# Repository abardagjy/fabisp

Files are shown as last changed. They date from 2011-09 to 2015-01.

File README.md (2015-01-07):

# FabISP



_FabISPkey V1.0 (current revision is V2.3, after V2.2, V2.1, V2.0 and V1.1)_

The geneology of the FabISP design is interesting in its own right; Neil's [FabISP](http://academy.cba.mit.edu/classes/electronics_production/index.html) is based on David Mellis's [FabISP](http://fab.cba.mit.edu/content/projects/fabisp/) which is based on Limor's [USBTinyISP](http://www.ladyada.net/make/usbtinyisp/index.html) which is based on Dick Streefland's [USBTiny](http://dicks.home.xs4all.nl/avr/usbtiny/).

## FabISPkey

### Design

I decided I could make a few tweaks to the design, electrically and mechanically. First, I tried out my mechanical modifications before I dove too deeply into electrical modification. Next, I redrew David's schematic in EagleCAD. I replaced the USB connector with a board edge USB connector from the SparkFun library. I also replaced the crystal with one that I had on hand, which ended up being a mistake, and in later designs I used the one in the Fab inventory, which is smaller. All the parts can be found in the standard fab inventory.

<table align="center">
<tbody>
<tr>
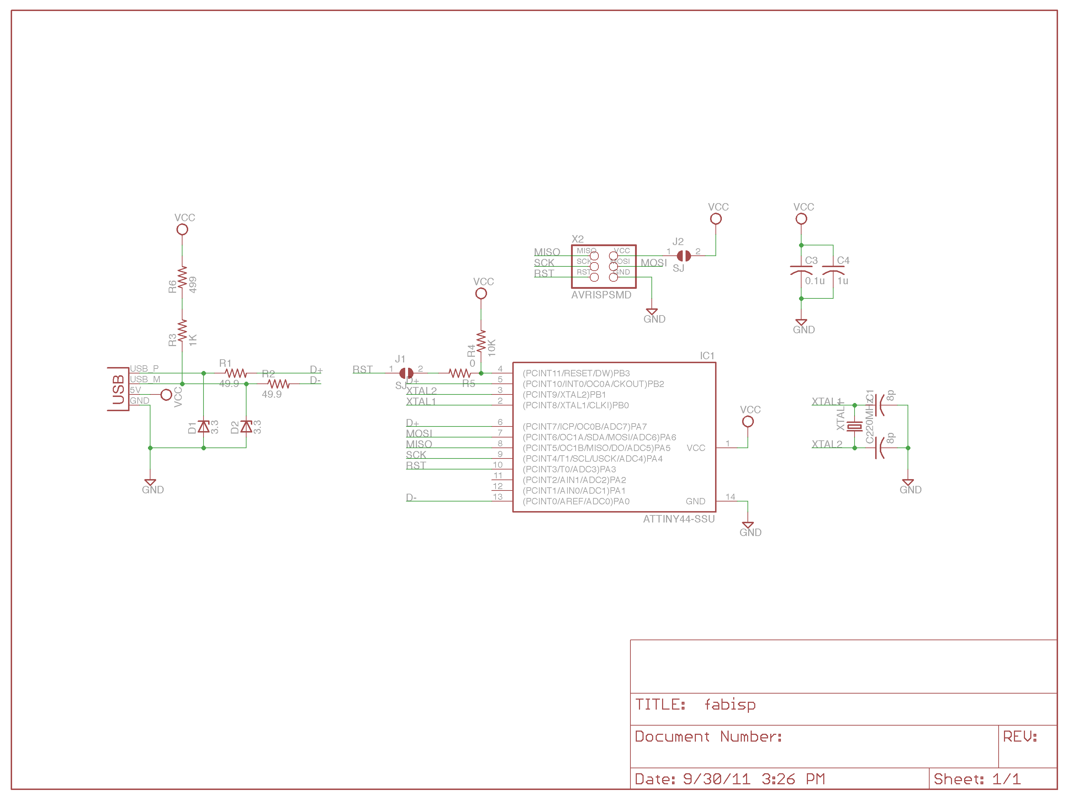
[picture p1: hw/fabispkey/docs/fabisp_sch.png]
fabispkey_sch
<td></td>
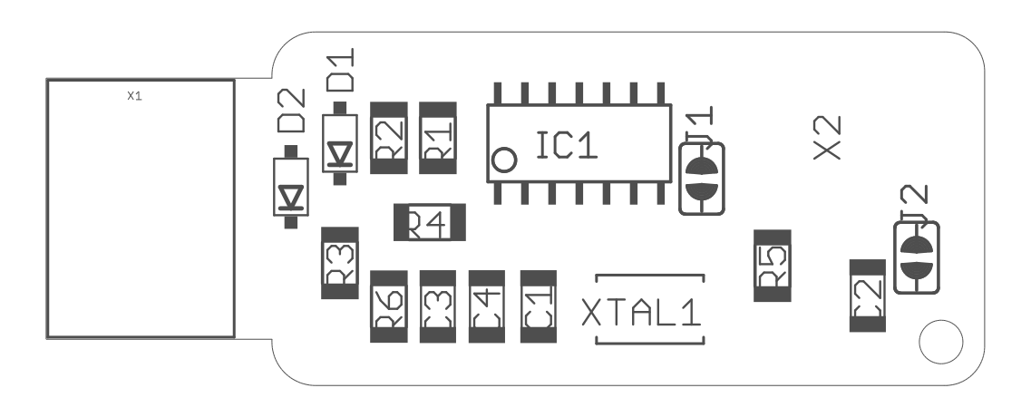
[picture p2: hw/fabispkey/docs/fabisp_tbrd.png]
fabispkey_tbrd
<td></td>
</tr>
</tbody>
</table>

_Version 2.3 FabISPkey, schematic and assembly drawing_

In general, I made the total footprint a little smaller and replaced the mini-USB connector with a board connector. In a second design, I added a level shifter to accommodate programming of low voltage (1.8V) targets.

Some notes: I use a ground pour, because I figure if I'm going to have extra copper on my board, I'd like to know what it's connected to. The pour has 0.020 spacing, so slightly more than one pass with a 0.015 endmill cuts it out. 

### Fabrication

Because the connector, the design requires complete copper removal (-1 contours flag). Also, the board connector is a little wiggily, so, it's sometimes helpful to glue or tape a small (0.010") shim on the underside of the connector. I use a piece of an old credit card and the same double sided tape used to affix the boards to the Modella.

When populating the board, be sure to observe polarity on for the zeners and the ATtiny. I did not leave thermal reliefs on the ground pour (I find they don't come out well on the Modella, also decreases cut time). Because there are no thermals, be sure to avoid cold solder joints on all components connected to the ground plane. 

<table align="center">
<tbody>
<tr>
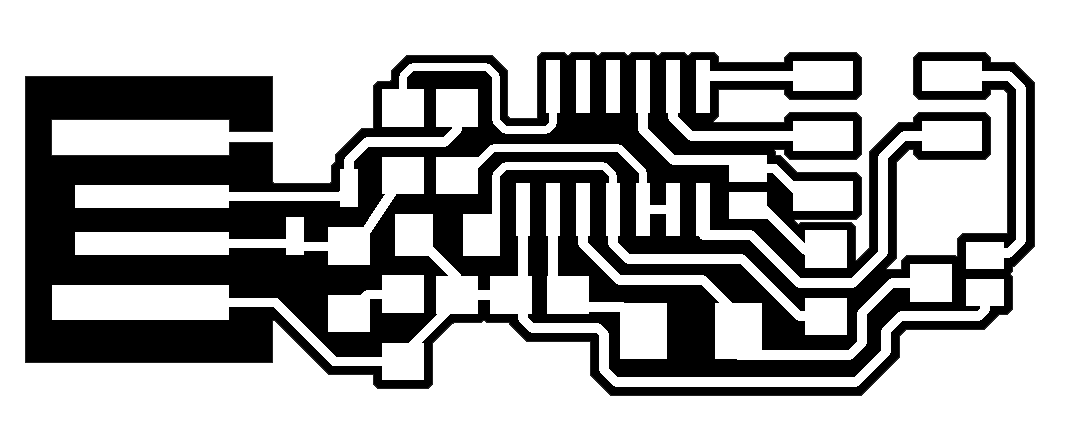
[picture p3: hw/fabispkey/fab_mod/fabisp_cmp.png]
fabispkey_cmp
<td></td>
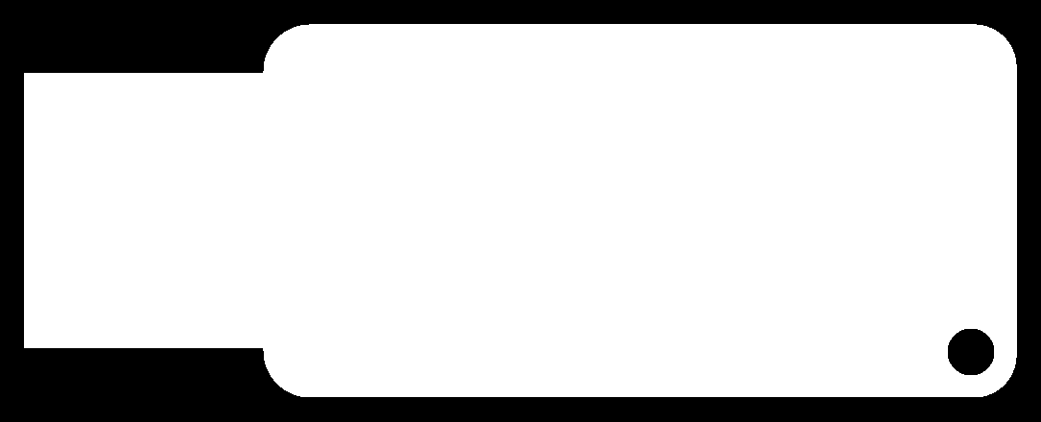
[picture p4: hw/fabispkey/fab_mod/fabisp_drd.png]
fabispkey_drd
<td></td>
</tr>
</tbody>
</table>

_Version 2.3 FabISPkey_

If you'd like to play along at home, you can grab fabbable PNGs above and you can get the design files in this content directory.

### Programming

Since my design is electrically similar to Neil and David's, programming is very similar. 

1.  Solder the reset jumper (the one closest to the processor)
2.  Power the board (using a USB port, or USB charger)
3.  Using a standard programming cable, connect your programmer to be to another programmer (connect Pin 1 to Pin 1, Pin 2 to 2 and so on)
<li>Program it with another programmer (make hex, make fuse, make program)
4.  Unplug the programming cable, remove power, and desolder the jumper
5.  Spawn more programmers!

## FabISPlokey

One of the main motivations of the board re-design was to incorporate a level shifter to allow the programming of 1.8V targets. This is a particularly important feature (especially for this class) because it allows the use of a single cell to power designs.

The Lokey dispenses with the 3.3V zeners and adds a 3.3V regulator (in the Fab inventory). The microcontroller now runs on 3.3V, no need for the zeners to make it USB compliant. 

Having a 3.3V Vcc is required to use the level shifter I selected, the Texas Instruments [TXB0104](http://www.ti.com/lit/ds/symlink/txb0104.pdf). The TX0104 is available in a 14 SOIC package (which is easily fabricatable on the Modella), and if you ask nicely, TI will happily sample a few parts to you. 

<table align="center">
<tbody>
<tr>
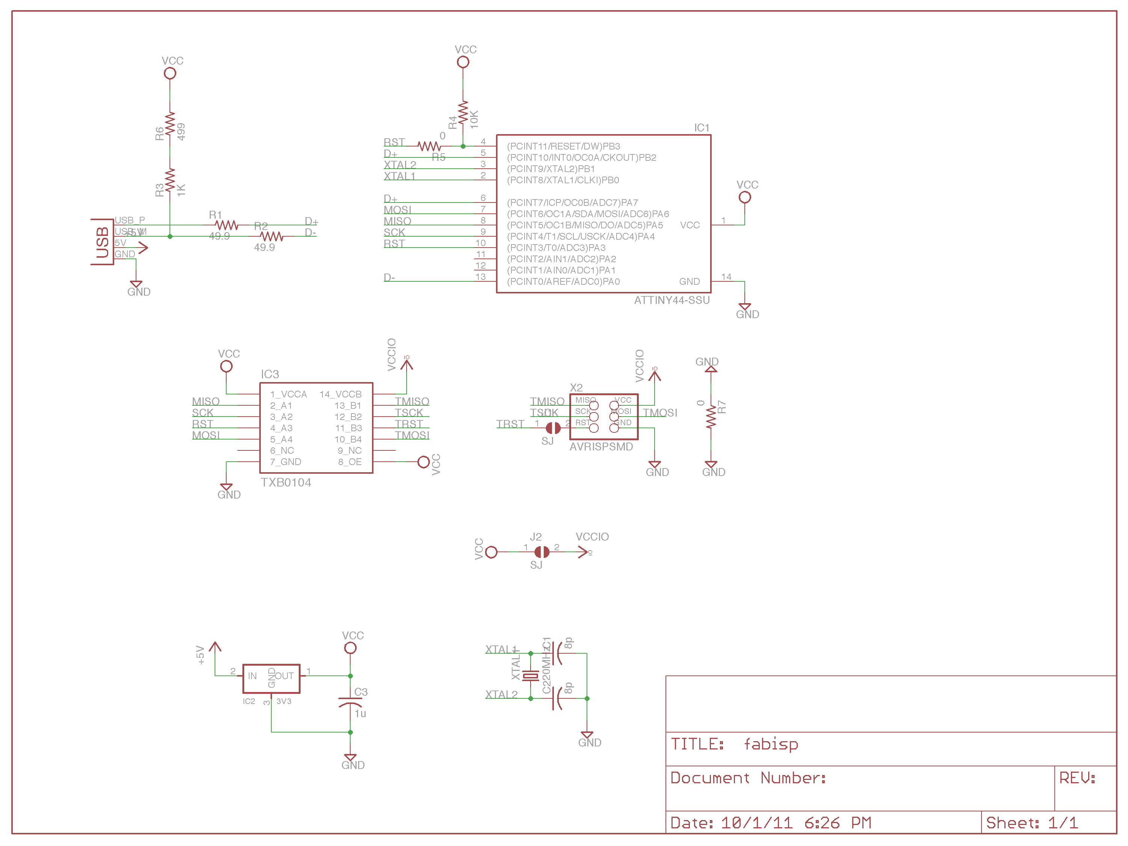
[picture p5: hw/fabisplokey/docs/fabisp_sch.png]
fabisplokey_sch
<td></td>
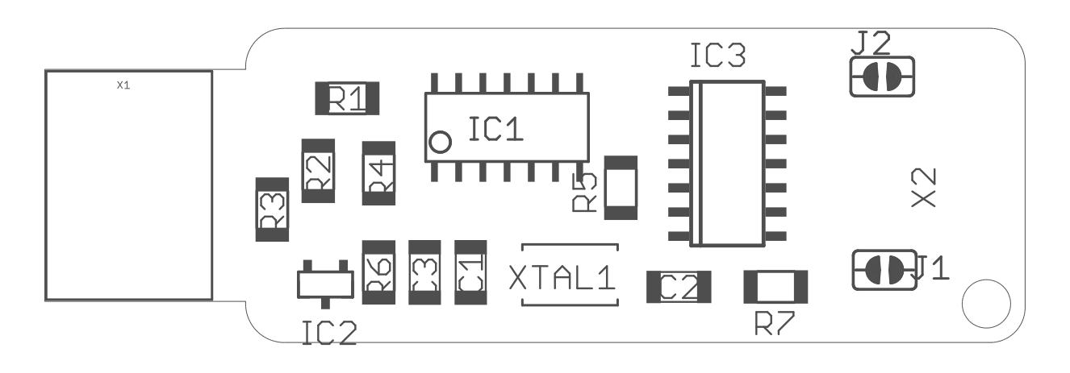
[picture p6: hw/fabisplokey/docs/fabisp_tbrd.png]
fabisplokey_tbrd
<td></td>
</tr>
</tbody>
</table>

_Version 2.3 FabISPkey, schematic and assembly drawing_

<table align="center"><tbody>
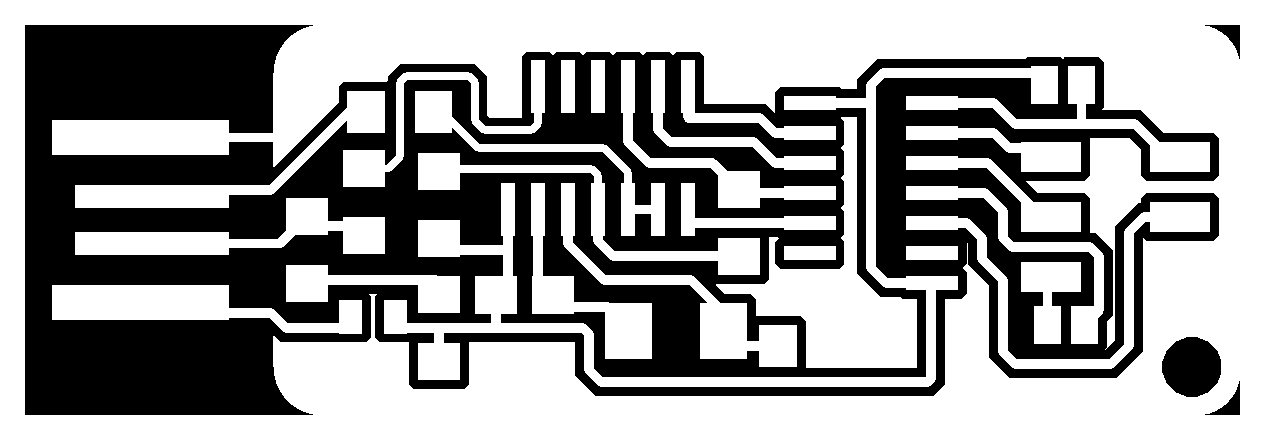
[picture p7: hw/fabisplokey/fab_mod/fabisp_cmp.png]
fabisplokey_cmp
<tr><td></td>
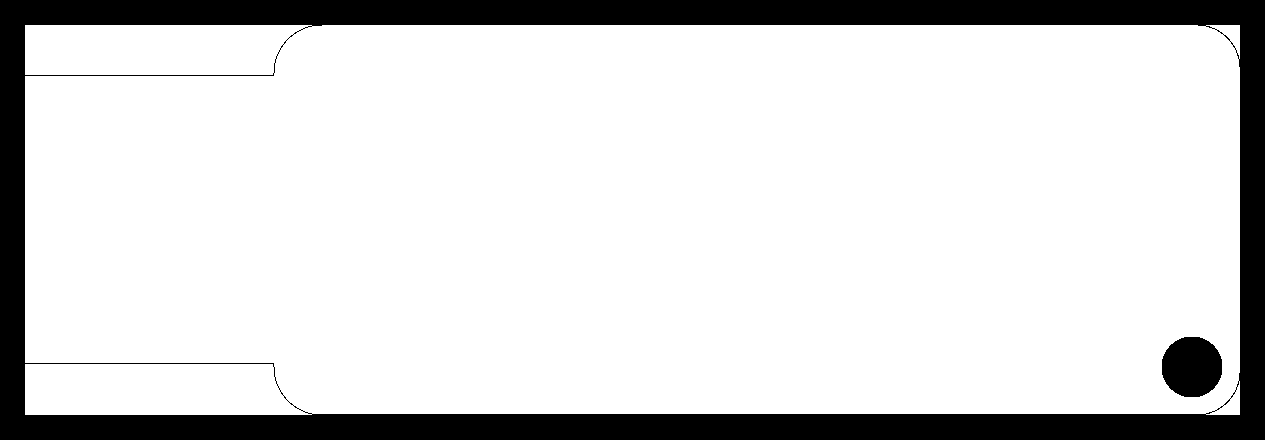
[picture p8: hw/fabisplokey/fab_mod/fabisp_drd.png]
fabisplokey_drd
<td></td>
</tr>
</tbody>
</table>

_Version 2.1 FabISPlokey_

I do not have any 1.8V targets to try this design on and should be considered an untested reference design (though it should work), Nevertheless, if you'd like to try it out yourself, you can grab the PNGs above or from the repo (it's in the same project as the Key).

_Created by [Andy Bardagjy](http://bardagjy.com) 12/19/2011, modified 1/7/2015_

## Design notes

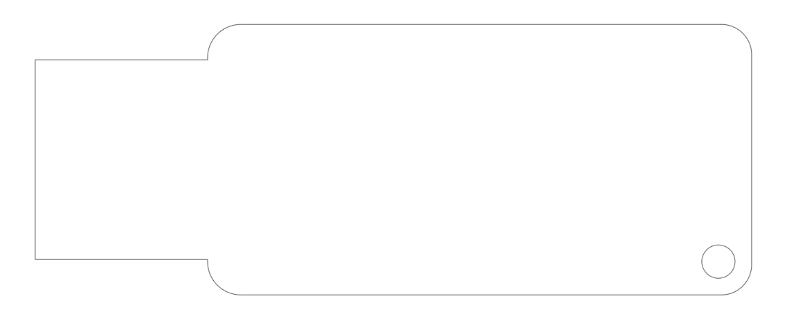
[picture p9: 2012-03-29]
hw/fabispkey/docs/fabisp_bbrd.png

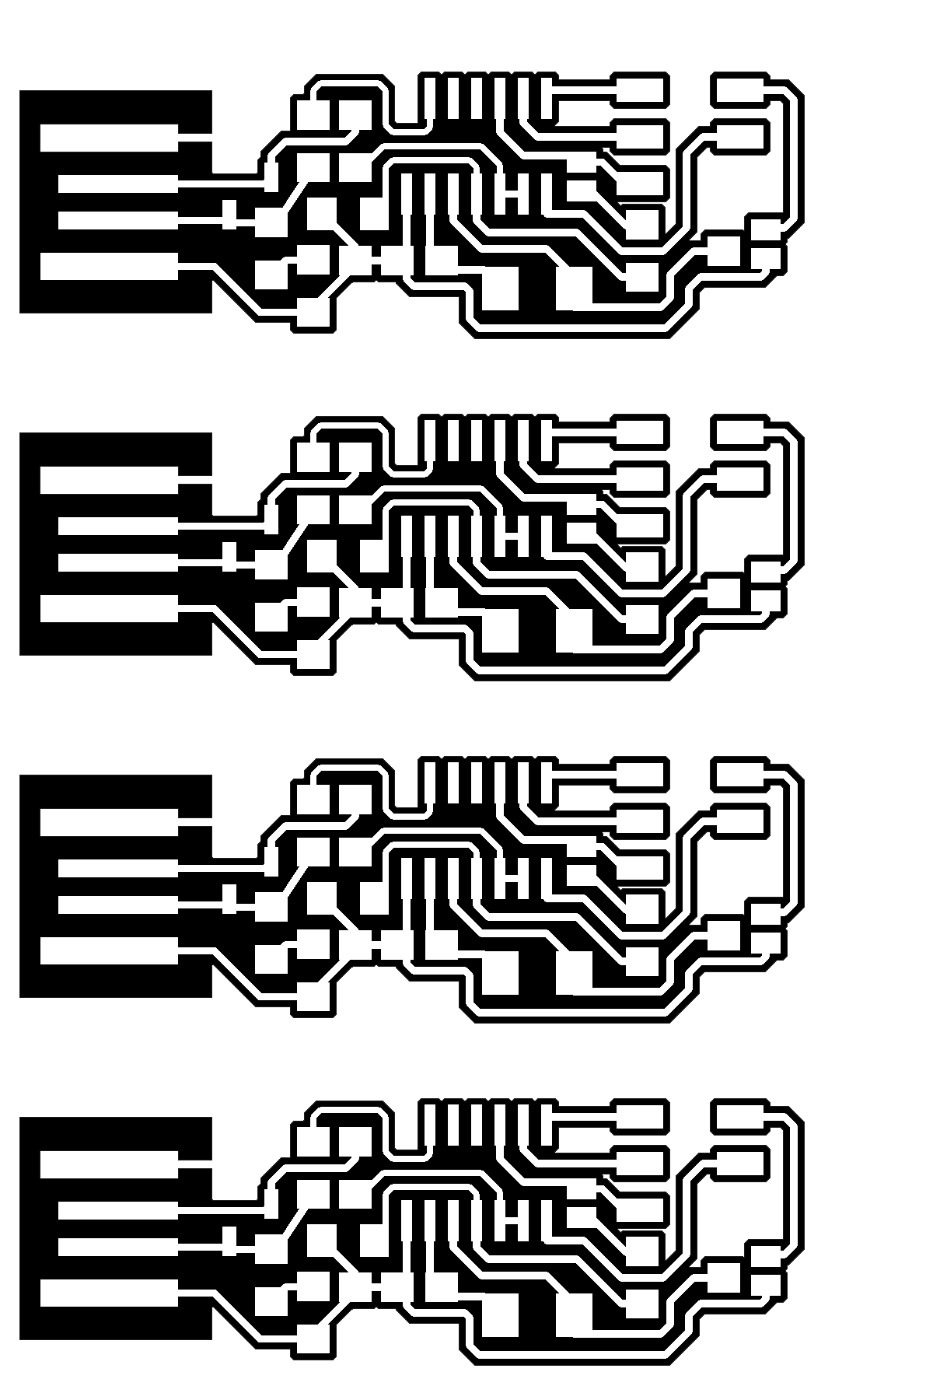
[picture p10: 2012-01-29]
hw/fabispkey/fab_mod/4up_cmp.png

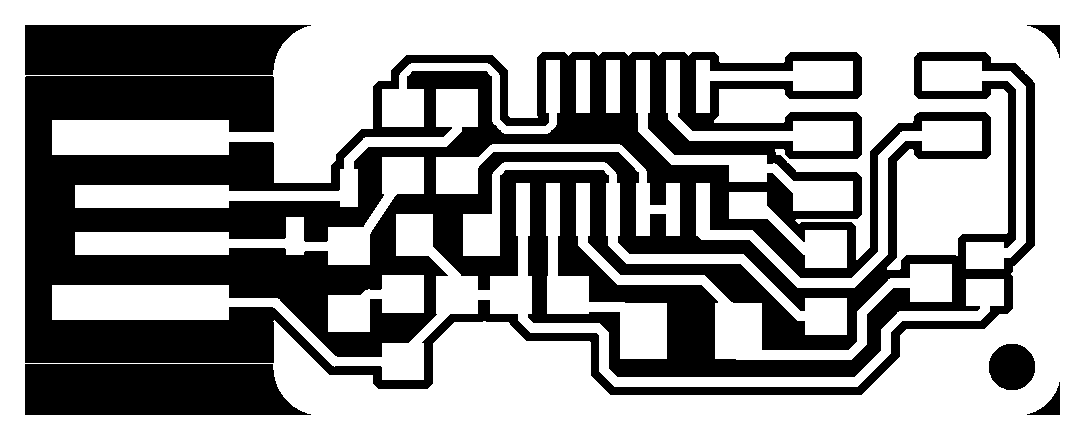
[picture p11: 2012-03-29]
hw/fabispkey/fab/fabisp_cmp.png

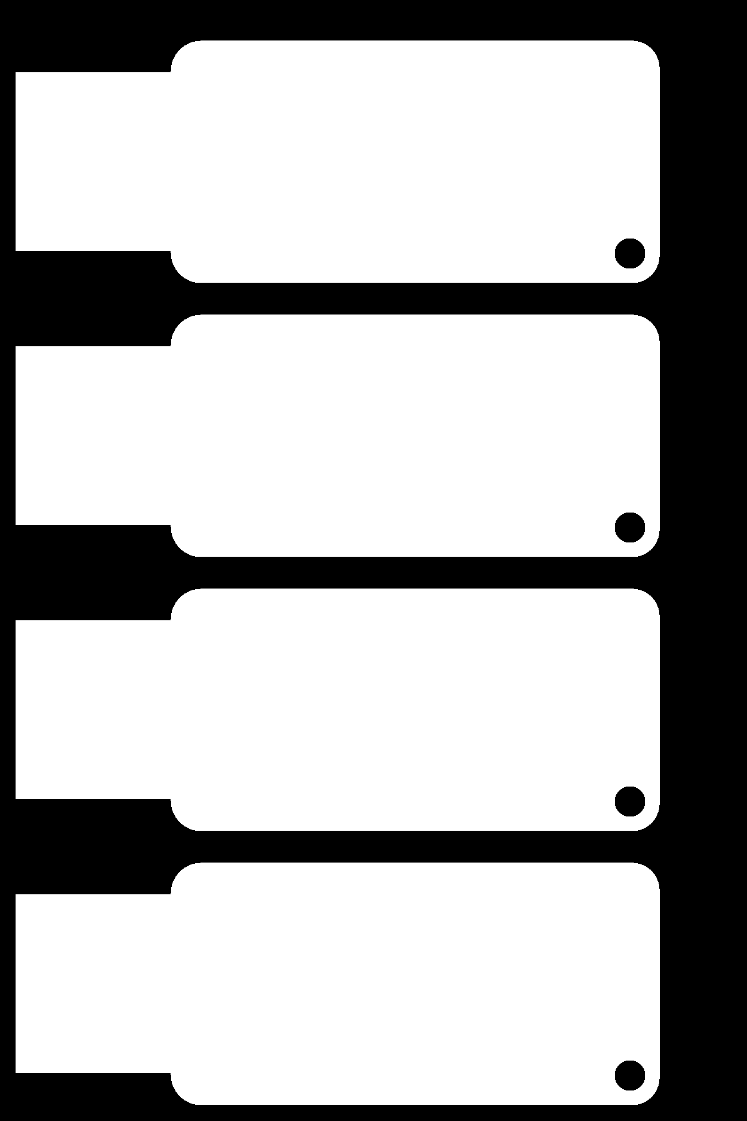
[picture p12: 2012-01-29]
hw/fabispkey/fab_mod/4up_drd.png

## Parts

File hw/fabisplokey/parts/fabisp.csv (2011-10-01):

Quantity | Digikey # | Internal #
2 |  | 8p C1206 C1 C2
1 |  | 1u C1206 C3
1 |  | ATTINY44-SSU SOIC14 IC1
1 |  | 3V3 SOT23 IC2
1 |  | TXB0104 SO14 IC3
2 |  | SJ SJFAB J1 J2
2 |  | 49.9 R1206 R1 R2
1 |  | 1K R1206 R3
1 |  | 10K R1206 R4
2 |  | 0 R1206 R5 R7
1 |  | 499 R1206 R6
1 |  | USBPCB USB-A-PCB X1
1 |  | AVRISPSMD 2X03SMD X2
1 |  | 20MHz 2-SMD-5X3MM XTAL1

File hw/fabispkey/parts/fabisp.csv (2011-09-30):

Quantity | Digikey # | Internal #
2 |  | 8p C1206 C1 C2
1 |  | 0.1u C1206 C3
1 |  | 1u C1206 C4
2 |  | 3.3 SOD123 D1 D2
1 |  | ATTINY44-SSU SOIC14 IC1
2 |  | SJ SJFAB J1 J2
2 |  | 49.9 R1206 R1 R2
1 |  | 1K R1206 R3
1 |  | 10K R1206 R4
1 |  | 0 R1206 R5
1 |  | 499 R1206 R6
1 |  | USBPCB USB-A-PCB X1
1 |  | AVRISPSMD 2X03SMD X2
1 |  | 20MHz 2-SMD-5X3MM XTAL1

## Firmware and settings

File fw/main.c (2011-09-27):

/* Name: main.c
 * Project: FabISP Firmware
 * Author: David A. Mellis
 * Based on Work By: Dick Streefland and Christian Starkjohann
 * Creation Date: 2009-11-18
 * Tabsize: 4
 * Copyright: (c) 2006-2008 Dick Streefland
 * Copyright: (c) 2008 by OBJECTIVE DEVELOPMENT Software GmbH
 * License: GNU GPL v2 (see License.txt), GNU GPL v3
 */

/*
This example should run on most AVRs with only little changes. No special
hardware resources except INT0 are used. You may have to change usbconfig.h for
different I/O pins for USB. Please note that USB D+ must be the INT0 pin, or
at least be connected to INT0 as well.
*/

#include <avr/io.h>
#include <avr/wdt.h>
#include <avr/interrupt.h>  /* for sei() */
#include <util/delay.h>     /* for _delay_ms() */

#include <avr/pgmspace.h>   /* required by usbdrv.h */
#include "usbdrv.h"
#include "oddebug.h"        /* This is also an example for using debug macros */

typedef	unsigned char	byte_t;
typedef	unsigned int	uint_t;

enum
{
	// Generic requests
	USBTINY_ECHO,		// 0x00: echo test
	USBTINY_READ,		// 0x01: read byte (wIndex:address)
	USBTINY_WRITE,		// 0x02: write byte (wIndex:address, wValue:value)
	USBTINY_CLR,		// 0x03: clear bit (wIndex:address, wValue:bitno)
	USBTINY_SET,		// 0x04: set bit (wIndex:address, wValue:bitno)
	// Programming requests
	USBTINY_POWERUP,	// 0x05: apply power (wValue:SCK-period, wIndex:RESET)
	USBTINY_POWERDOWN,	// 0x06: remove power from chip
	USBTINY_SPI,		// 0x07: issue SPI command (wValue:c1c0, wIndex:c3c2)
	USBTINY_POLL_BYTES,	// 0x08: set poll bytes for write (wValue:p1p2)
	USBTINY_FLASH_READ,	// 0x09: read flash (wIndex:address)
	USBTINY_FLASH_WRITE,	// 0x0A: write flash (wIndex:address, wValue:timeout)
	USBTINY_EEPROM_READ,	// 0x0B: read eeprom (wIndex:address)
	USBTINY_EEPROM_WRITE,	// 0x0C: write eeprom (wIndex:address, wValue:timeout)
};

// ----------------------------------------------------------------------
// Programmer output pins:
//	LED	PA1
//	RESET	PA3
//	SCK	PA4
//	MOSI	PA6
// ----------------------------------------------------------------------
#define	PORT		PORTA
#define	DDR		DDRA
#define	POWER_MASK	0x02
#define	RESET_MASK	(1 << 3)
#define	SCK_MASK	(1 << 4)
#define	MOSI_MASK	(1 << 6)
#define ALL_MASK	(POWER_MASK | RESET_MASK | SCK_MASK | MOSI_MASK)

// ----------------------------------------------------------------------
// Programmer input pins:
//	MISO	PA5
// ----------------------------------------------------------------------
#define	PIN		PINA
#define	MISO_MASK	(1 << 5)

// ----------------------------------------------------------------------
// Local data
// ----------------------------------------------------------------------
static	byte_t		sck_period;	// SCK period in microseconds (1..250)
static	byte_t		poll1;		// first poll byte for write
static	byte_t		poll2;		// second poll byte for write
static	uint_t		address;	// read/write address
static	uint_t		timeout;	// write timeout in usec
static	byte_t		cmd0;		// current read/write command byte
static	byte_t		cmd[4];		// SPI command buffer
static	byte_t		res[4];		// SPI result buffer

// ----------------------------------------------------------------------
// Delay exactly <sck_period> times 0.5 microseconds (6 cycles).
// ----------------------------------------------------------------------
__attribute__((always_inline))
static	void	delay ( void )
{
	asm volatile(
		"	mov	__tmp_reg__,%0	\n"
		"0:	rjmp	1f		\n"
		"1:	nop			\n"
		"	dec	__tmp_reg__	\n"
		"	brne	0b		\n"
		: : "r" (sck_period) );
}

// ----------------------------------------------------------------------
// Issue one SPI command.
// ----------------------------------------------------------------------
static	void	spi ( byte_t* cmd, byte_t* res )
{
	byte_t	i;
	byte_t	c;
	byte_t	r;
	byte_t	mask;

	for	( i = 0; i < 4; i++ )
	{
		c = *cmd++;
		r = 0;
		for	( mask = 0x80; mask; mask >>= 1 )
		{
			if	( c & mask )
			{
				PORT |= MOSI_MASK;
			}
			delay();
			PORT |= SCK_MASK;
			delay();
			r <<= 1;
			if	( PIN & MISO_MASK )
			{
				r++;
			}
			PORT &= ~ MOSI_MASK;
			PORT &= ~ SCK_MASK;
		}
		*res++ = r;
	}
}

// ----------------------------------------------------------------------
// Create and issue a read or write SPI command.
// ----------------------------------------------------------------------
static	void	spi_rw ( void )
{
	uint_t	a;

	a = address++;
	if	( cmd0 & 0x80 )
	{	// eeprom
		a <<= 1;
	}
	cmd[0] = cmd0;
	if	( a & 1 )
	{
		cmd[0] |= 0x08;
	}
	cmd[1] = a >> 9;
	cmd[2] = a >> 1;
	spi( cmd, res );
}

static	uchar	dataBuffer[8];  /* buffer must stay valid when usbFunctionSetup returns */
// ----------------------------------------------------------------------
// Handle a non-standard SETUP packet.
// ----------------------------------------------------------------------
extern	usbMsgLen_t	usbFunctionSetup ( byte_t data[8] )
{
	byte_t	bit;
	byte_t	mask;
	byte_t*	addr;
	byte_t	req;
        byte_t	i;

	// Generic requests
	req = data[1];
	if	( req == USBTINY_ECHO )
	{
        	for	( i = 0; i < 8; i++ )
                {
                	dataBuffer[i] = data[i];
                }
        	usbMsgPtr = dataBuffer;
		return 8;
	}
	addr = (byte_t*) (int) data[4];
	if	( req == USBTINY_READ )
	{
		dataBuffer[0] = *addr;
        	usbMsgPtr = dataBuffer;
		return 1;
	}
	if	( req == USBTINY_WRITE )
	{
		*addr = data[2];
		return 0;
	}
	bit = data[2] & 7;
	mask = 1 << bit;
	if	( req == USBTINY_CLR )
	{
		*addr &= ~ mask;
		return 0;
	}
	if	( req == USBTINY_SET )
	{
		*addr |= mask;
		return 0;
	}

	// Programming requests
	if	( req == USBTINY_POWERUP )
	{
		sck_period = data[2];
		mask = POWER_MASK;
		if	( data[4] )
		{
			mask |= RESET_MASK;
		}
		DDR  |= ALL_MASK;
		PORT = (PORT & ~ ALL_MASK) | mask;
		return 0;
	}
	if	( req == USBTINY_POWERDOWN )
	{
		PORT |= RESET_MASK;
		PORT &= ~ ALL_MASK;
		DDR  &= ~ ALL_MASK;
		return 0;
	}
	if	( ! PORT )
	{
		return 0;
	}
	if	( req == USBTINY_SPI )
	{
		spi( data + 2, dataBuffer );
        	usbMsgPtr = dataBuffer;
		return 4;
	}
	if	( req == USBTINY_POLL_BYTES )
	{
		poll1 = data[2];
		poll2 = data[3];
		return 0;
	}
	address = * (uint_t*) & data[4];
	if	( req == USBTINY_FLASH_READ )
	{
		cmd0 = 0x20;
		return USB_NO_MSG; // usbFunctionRead() will be called to get the data
	}
	if	( req == USBTINY_EEPROM_READ )
	{
		cmd0 = 0xa0;
		return USB_NO_MSG; // usbFunctionRead() will be called to get the data
	}
	timeout = * (uint_t*) & data[2];
	if	( req == USBTINY_FLASH_WRITE )
	{
		cmd0 = 0x40;
		return USB_NO_MSG;	// data will be received by usbFunctionWrite()
	}
	if	( req == USBTINY_EEPROM_WRITE )
	{
		cmd0 = 0xc0;
		return USB_NO_MSG;	// data will be received by usbFunctionWrite()
	}
	return 0;
}

// ----------------------------------------------------------------------
// Handle an IN packet.
// ----------------------------------------------------------------------
extern	byte_t	usbFunctionRead ( byte_t* data, byte_t len )
{
	byte_t	i;

	for	( i = 0; i < len; i++ )
	{
		spi_rw();
		data[i] = res[3];
	}
	return len;
}

// ----------------------------------------------------------------------
// Handle an OUT packet.
// ----------------------------------------------------------------------
extern	byte_t	usbFunctionWrite ( byte_t* data, byte_t len )
{
	byte_t	i;
	uint_t	usec;
	byte_t	r;

	for	( i = 0; i < len; i++ )
	{
		cmd[3] = data[i];
		spi_rw();
		cmd[0] ^= 0x60;	// turn write into read
		for	( usec = 0; usec < timeout; usec += 32 * sck_period )
		{	// when timeout > 0, poll until byte is written
			spi( cmd, res );
			r = res[3];
			if	( r == cmd[3] && r != poll1 && r != poll2 )
			{
				break;
			}
		}
	}
        
        return 1;
}

/* ------------------------------------------------------------------------- */

int main(void)
{
uchar   i;

    wdt_enable(WDTO_1S);
    /* Even if you don't use the watchdog, turn it off here. On newer devices,
     * the status of the watchdog (on/off, period) is PRESERVED OVER RESET!
     */
    DBG1(0x00, 0, 0);       /* debug output: main starts */
    /* RESET status: all port bits are inputs without pull-up.
     * That's the way we need D+ and D-. Therefore we don't need any
     * additional hardware initialization.
     */
    odDebugInit();
    usbInit();
    usbDeviceDisconnect();  /* enforce re-enumeration, do this while interrupts are disabled! */
    i = 0;
    while(--i){             /* fake USB disconnect for > 250 ms */
        wdt_reset();
        _delay_ms(1);
    }
    usbDeviceConnect();
    sei();
    DBG1(0x01, 0, 0);       /* debug output: main loop starts */
    for(;;){                /* main event loop */
        DBG1(0x02, 0, 0);   /* debug output: main loop iterates */
        wdt_reset();
        usbPoll();
    }
    return 0;
}

/* ------------------------------------------------------------------------- */

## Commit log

2011-09-27 initial commit of repo
    [fabisp.brd, fabisp.csv, fabisp.sch]
2011-09-28 branching to a "compat" hardware and a "lo(voltage" hardware
    [fabisp.brd, fabisp.csv, fabisp.sch]
2011-09-28 finishing up the aftermath of the commit
    [fabisp.brd, fabisp.csv, fabisp.sch]
2011-09-28 renamed the compatible hardware to fabispkey, low voltage stuff to fabisplokey
    [fabisp.brd, fabisp.csv, fabisp.sch]
2011-09-28 changed to use xtal in fab inventory
    [fabisp.brd, fabisp.sch]
2011-09-30 broke 1.5K resistor into 1K+499 (in the fab inventory) also radiused corners
    [fabisp.brd, fabisp.csv, fabisp.sch]
2011-09-30 rotated isp header, made it a little smaller, made usb deeper for better contact
    [fabisp.brd, fabisp.sch]
2011-10-01 got a working version with the level shifter, made manufacturable parts for the fabispkey
    [fabisp.brd, fabisp.csv, fabisp.sch]
2011-10-03 changed one trace to be 16 mils instead of 12
    [fabisp.brd]
2011-10-10 made fabispkey a little smaller
    [fabisp.brd]
2011-12-08 modded the makefile to not produce solderside pngs, touched up files for production
2011-12-08 made small change in makefile to make cut time quicker. now the outline when exporting _cmp is white, this allows the use of an image editor to easily paintbucket fill areas which should not be clear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
2011-12-09 connected a previously disconnected groundplane
    [fabisp.brd]
